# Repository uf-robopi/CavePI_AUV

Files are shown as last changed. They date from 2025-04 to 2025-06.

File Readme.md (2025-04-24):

This repository contains the design files, operational codes, and digital twin system's packages for the **CavePI AUV** (Autonomous Underwater Vehicle) from the RoboPI group at ECE, UF. The paper is accepted for publication at the Robotics: Science and Systems (RSS-2025). 

<p align="center">
  cavepi_field
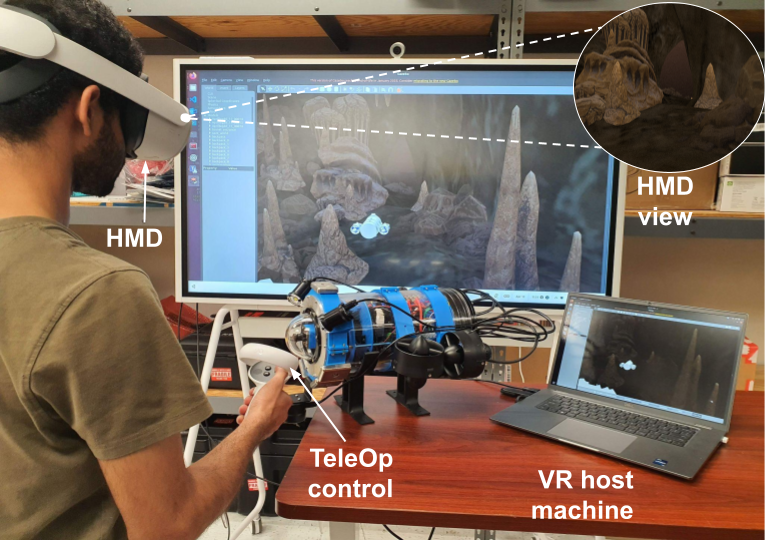
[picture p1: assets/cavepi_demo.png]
cavepi_demo
  
</p>

## Resources

- **Pointers:** [[ArXiv Pre-print]](https://arxiv.org/pdf/2502.05384) [[Project Page]](https://robopi.ece.ufl.edu/cavepi.html)  [[Video Demo]](https://youtu.be/9BPpB1nu98E)
- The subdirectories contain the following 
  - **CAD_designs:** Contains the SolidWork design files for all the parts used to build CavePI.
  - **auv_nano:** Contains the codes for CavePI's onboard Jetson device.
  - **auv_rpi:** Contains the codes for CavePI's onboard Raspberry Pi 5 device.
  - **auv_dt:** Contains the codes for ROS-Gazebo based digital twin (DT) of CavePI.

### License and Bibliography 
- Please check the LICENSE file 
- Citation entry:
	```
  @inproceedings{gupta2025demonstrating,
    title={Demonstrating CavePI: Autonomous Exploration of Underwater Caves by Semantic Guidance},
    author={Gupta, Alankrit and Abdullah, Adnan and Li, Xianyao and Ramesh, Vaishnav and Rekleitis, Ioannis and Islam, Md Jahidul},
    booktitle={Robotics: Science and Systems (RSS)},
    year={2025}
  }
	```

### Acknowledgements
This research is supported in part by the U.S. National Science Foundation (NSF) grants #2330416, #2024741, and #1943205; and the University of Florida (UF) Research grant #132763. We are thankful to Dr. Nare Karapetyan, Ruo Chen, and David Blow for facilitating our field trials at Ginnie open-water springs and Blue Grotto.

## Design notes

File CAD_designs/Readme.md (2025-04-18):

# SolidWork Design files of CavePI AUV

Due to large filesize of some parts, they are not uploaded directly to this repo. Please refer to this shared [Dropbox folder](https://www.dropbox.com/scl/fo/iza5p15aaolned5e47gp4/AAuj588nzsUPL_QK-2lGrOM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) to download all the files.

## Description

The parts are categorized into four groups.

- Exterior
  - Thruster
  - Sonar
  - Lights
  - ballast weights
- Interior (Computational enclosure)
  -  Battery junction
  -  Battery mounting plates (top, bottom, left, right, circular)
  -  Battery stack
  -  ESC
  -  Low light camera (downward camera)
  -  End cap
  -  O-ring flange
  -  Euro terminal strip
  -  Jetson Nano
  -  Mounting plate for Jetson Nano
  -  Raspberry Pi
  -  Mounting plate for Raspberry Pi
  -  Pixhawk
  -  Tether interface module
  -  Tube
-  Head
   - Fisheye camera
   - Dome connector
   - Dome retainer ring
   - Dome
 - Fasteners
   - Nuts, bolts, spacers and stand-offs

### Acknowledgements

We gratefully acknowledge the following entities for their the open-source CAD designs of various parts: Blue Robotics, GrabCAD, and McMaster-Carr.

| Part Name | 3D Model Owner / Referred From |
|---|---|
| Tube | Blue Robotics |
| End Cap | Blue Robotics |
| O-Ring Flange | Blue Robotics |
| Camera Low Light | Blue Robotics |
| Tether Interface Module | Blue Robotics |
| Basic ESC | Blue Robotics |
| Dome Retainer Ring | Blue Robotics |
| Dome | Blue Robotics |
| T200_Thruster | Blue Robotics |
| Sonar Bracket | Blue Robotics |
| Ping2 Sonar | Blue Robotics |
| Ballast Weight | Blue Robotics |
| Light | Blue Robotics |
| All fasteners | McMaster Carr |
| Jetson Nano | [GrabCAD](https://grabcad.com/library/nvidia-jetson-nano-2) |
| Raspberry Pi 5 | [GrabCAD](https://grabcad.com/library/raspberry-pi-5-2) |
| Pixhawk | [GrabCAD](https://grabcad.com/library/pixhawk-2-4-8-v1-flight-controller-1) |
| Fish-Eye Camera | [ArduCam](https://www.arducam.com/arducam-1080p-low-light-wdr-ultra-wide-angle-usb-camera-module-for-computer-2mp-cmos-imx291-160-degree-fisheye-mini-uvc-usb2-0-spy-webcam-boa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) |

## Example

The CAD assembly and the exploded view of CavePI is shown below:
<p align="center">
  cavepi_sys_gif
</p>

The 3D models of some of the parts in CavePI are shown below.
<p align="center">
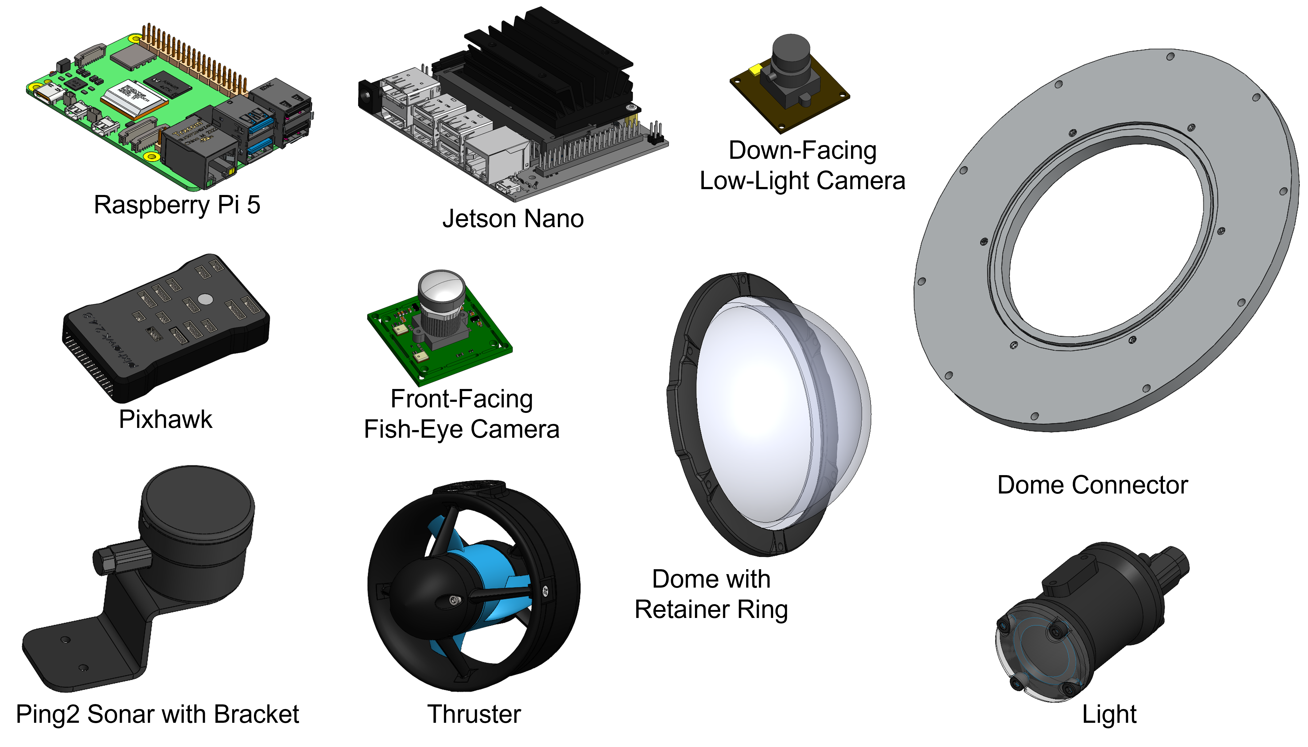
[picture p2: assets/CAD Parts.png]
CAD Parts
  
</p>

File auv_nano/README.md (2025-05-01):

# ROS2 Package for Perception of CavePI AUV

## Compatible Platform

The package is tested and verified on Jetson Orin Nano. It also runs on Jetson Nano 2GB with minimal modification in the code. Please refer to the `perception_utils.py` and comment/uncomment the codes where Jetson Nano and Jetson Orin Nano are mentioned.

Other specs (Platform dependent):

| | Jetson Nano 2GB | Jetson Orin Nano |
| ---  | ---  | --- |
| Ubuntu | 18.04 | 22.04 |
| ROS2 | Foxy | Humble |
| Jetpack | 4.6.3 | 6.0 |
| Python | 3.6.9 | 3.10.6 |
| Cuda | 10.2 | 12.1 |
| CuDNN | 8.2.1 | 9.1 |
| TensorRT | 8.2.1 | 8.6 |

## Usage

1. Clone the repo and place the `auv_nano` folder inside `~/ros2_ws/src/` directory of your jetson device.
2. Download the model weights from here: [Dropbox link](https://www.dropbox.com/scl/fo/6oin10fofx2k8ffhxluia/AJO9DvS03urmhyW1etIEWww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)
   
   You will find `.onnx` files as well as `.engine` files. If your platform matches the Jetson Nano 2GB configuration described above, you can directly use the `.engine` files. For different platforms such as Jetson Orin, download the `.onnx` file in your Jetson device and convert it to `.engine` format:
   ```sh
    /usr/src/tensorrt/bin/trtexec --onnx=<onnx_filename> --saveEngine=<engine_filename>
   ```
3. Create the `~/ros2_ws/src/auv_nano/weights/` directory and place the engine file there.
   ```sh
   mkdir -p ~/ros2_ws/src/auv_nano/weights/
   mv <path_to_your_engine_file> ~/ros2_ws/src/auv_nano/weights/
   ```
5. Set the `engine_filename` in `detector.py`. The default is `mobilenet.engine`.
6. Connect the two cameras to USB ports of your Jetson device. Check their port number using:
    ```sh
    v4l2-ctl --list-devices
    ```
7. Update the port numbers: `FRONT_CAMERA_INDEX` and `DOWN_CAMERA_INDEX` in `config/config.yaml`.  

8. Build the ROS package.
   ```sh
   cd ~/ros2_ws/
   colcon build --packages-select auv_nano
   ```
9. Execute the launch file. It will run the detector and planner node.
   ```sh
   ros2 launch auv_nano detector_and_planner.launch.py
   ```
   If a line is detected from the downward camera, the planner will send control commands to Raspberry Pi. Please refer to the `auv_rpi` folder to setup the Raspberry Pi codes.

## Example

If a caveline is detected, the `/processed_image` topic should look like the example below. Note that, the AUV is in motion and the blue arrow is indicating the next waypoint. 
<p align="center">
  Detection Tank
</p>

## Troubleshoot
Q: How to install pycuda on Jetson devices?

`pip install pycuda`

`fatal error: cuda.h: No such file or directory`

The following commands do the trick in Orin nano:

```sh
export PATH=/usr/local/cuda/bin:$PATH
sudo apt-get install python3-dev
pip install numpy
export CUDA_ROOT=/usr/local/cuda
pip install pycuda
```

Also see similar solutions reported across the community:
* https://forums.developer.nvidia.com/t/modulenotfounderror-no-module-named-pycuda-driver/204031
* https://stackoverflow.com/questions/52195608/src-cpp-cuda-hpp1410-fatal-error-cuda-h-no-such-file-or-directory/52604456

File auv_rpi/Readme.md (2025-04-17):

# ROS2 Package for Autopilot of CavePI AUV

## Compatible Platform

The package is tested and verified on Raspberry Pi 5 with ROS2 Humble.

## Connections
Connect the three USB ports of Raspberry Pi 5 to the ethernet port of Jetson Nano, micro USB port of the Pixhawk, and a USB to UART device to connect with the Ping2 sonar.

## Usage

1. Clone the repo and place the `auv_rpi` folder inside `~/ros2_ws/src/` directory of your Raspberry Pi 5.
2. Build the ROS package.
   ```sh
   cd ~/ros2_ws/
   colcon build --packages-select auv_rpi
   ```
3. Execute the launch file.
   ```sh
   ros2 launch auv_rpi cavepi_auv.launch.py
   ```
   If a caveline is detected from the downward camera, the AUV will start following the caveline.

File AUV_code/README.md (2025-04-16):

# ROS2 Package for Perception and Control of CavePI AUV

## Compatible Platform
Jetson Orin Nano 8GB

Jetpack 6

Python 3.10

Cuda xx

Tensor RT xx

## Usage:

1. Download and place this folder inside your `ros2_ws/src` directory.
2. Download the model weights from here: [Dropbox link](www.somelink.com)
   
   You will find .onnx files as well as .engine files. If your platform matches the configuration described above, you can directly use the .engine files. Otherwise, download the .onnx file in your Jetson device and convert it to .engine format:
   ```sh
    /usr/src/tensorrt/bin/trtexec --onnx=<onnx_filename> --saveEngine=<engine_filename>
   ```
4. Build the ROS package.
   ```sh
   colcon build --packages-select <package_name>
   ```
5. Run the caveline detector node.
   ```sh
   ros2 run detector caveline_detection_main.py
   ```

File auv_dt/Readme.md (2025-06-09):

# Digital Twin of CavePI AUV

## Compatible Platform

The packages are tested on ROS Noetic with Gazebo Classic.

## Additional Packages Installation
1. Install the `mavros` and `teleop-twist-keyboard` packages for the respective ROS version.
    ```sh
   sudo apt install ros-noetic-mavros ros-noetic-mavros-extras
   sudo apt install ros-noetic-teleop-twist-keyboard
   ```
   In case if you are using any other version of ROS than Noetic, please replace `noetic` with the correct version of ROS.
2. Install the `scipy` package with version >= 1.6.
   ```sh
   sudo apt install python3-pip
   pip3 install --user --upgrade scipy
   ```
   
## Usage

1. Clone the repo and place the four packages inside `~/catkin_ws/src/` directory in your local computer.
2. Download the 3D models of the CavePI links from here: [Dropbox link](https://www.dropbox.com/scl/fo/h16z4oh9wp337o5n7fm5i/AFeJVwF5MsPjYP4ErddTO0g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)
3. You will find a folder named `meshes` in the link. Download the folder and place it inside `~/catkin_ws/src/cavepi_description/`.
4. Build and source the ROS workspace.
   ```sh
   cd ~/catkin_ws/
   catkin_make
   source devel/setup.bash
   ```
6. For visualizing the digital twin model in RViz, run a ROS launch file:
   ```sh
   roslaunch cavepi_bringup display.launch
   ```
7. For autonomous caveline following, run a ROS launch file:
   ```sh
   roslaunch cavepi_bringup cavepi_auv.launch
   ```
8. For teleopration, run a ROS launch file:
   ```sh
   roslaunch cavepi_bringup cavepi_rov.launch
   ```
   And, also run a teleoperation node in another terminal window:
   ```sh
   rosrun cavepi_controller cavepi_teleop_keyboard.py
   ```
   By operating the keys as mentioned in the teleoperation node, digital twin can be controlled in the Gazebo environment.

### Acknowledgements

We gratefully acknowledge the [LoCO-AUV](https://github.com/loco-auv) for their open-source digital twin simulator.

## Example

The autonomous caveline following capability of the CavePI's digital twin is shown below. A red color caveline is arranged in a hexagonal shape at the bottom and CavePI is following it. Please note that CavePI's downward-facing camera view is also presented at the top-left corner of the gif below.
<p align="center">
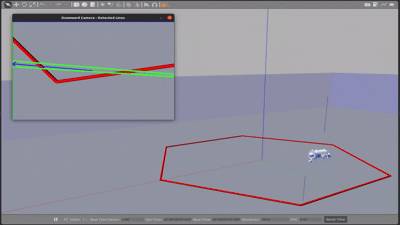
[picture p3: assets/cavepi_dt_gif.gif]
cavepi_dt_gif
  
</p>

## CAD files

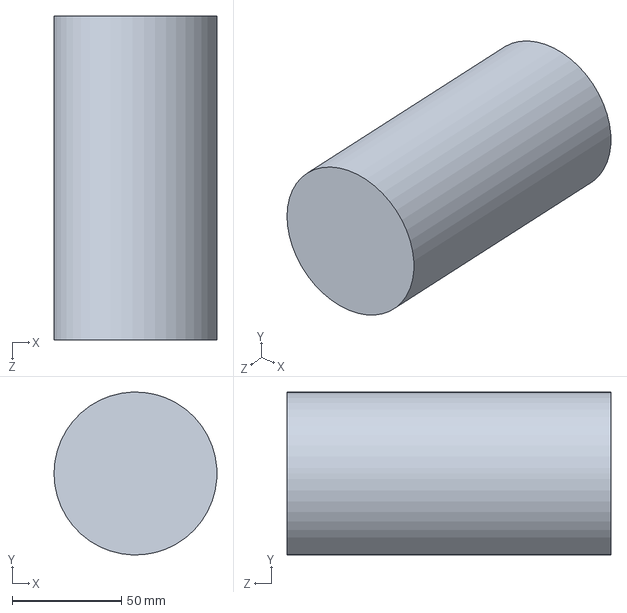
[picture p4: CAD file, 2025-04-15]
CAD_designs/Computational Enclosure/Battery Stack.SLDPRT
74.5 x 74.5 x 148.0 mm

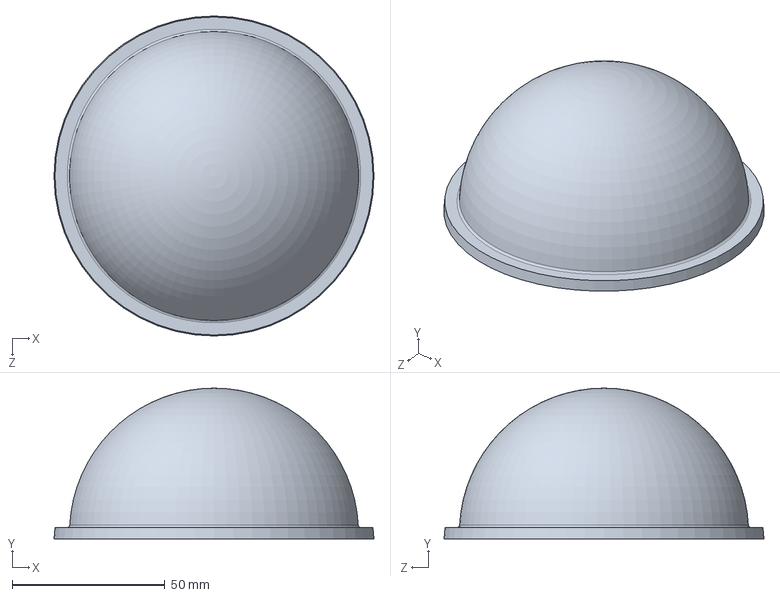
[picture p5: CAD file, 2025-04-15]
CAD_designs/Head/Dome.SLDPRT
104.7 x 49.3 x 104.7 mm

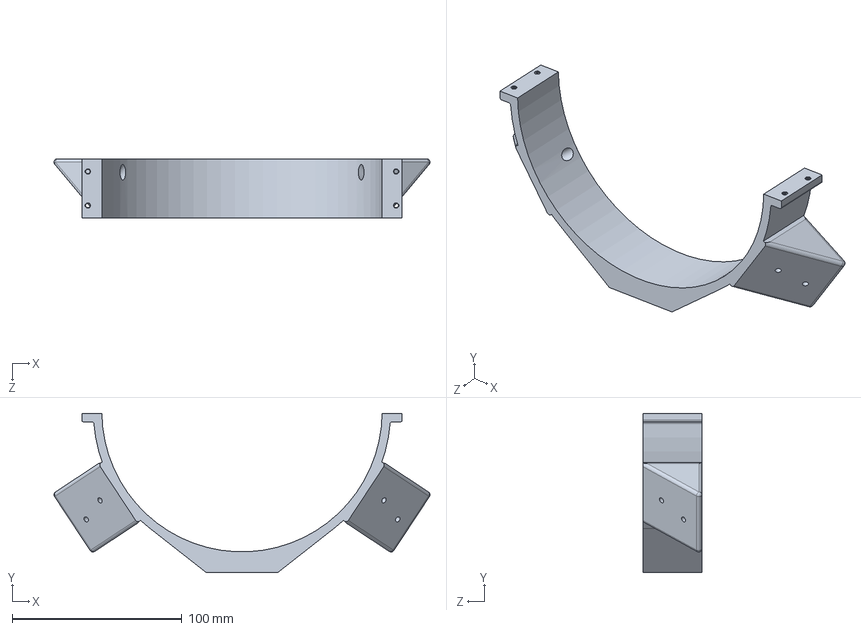
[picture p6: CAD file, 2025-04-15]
CAD_designs/Thrusters, Sonar, Lights, and Weights/Clamp for Sonar_Top.SLDPRT
221.5 x 93.8 x 35.0 mm

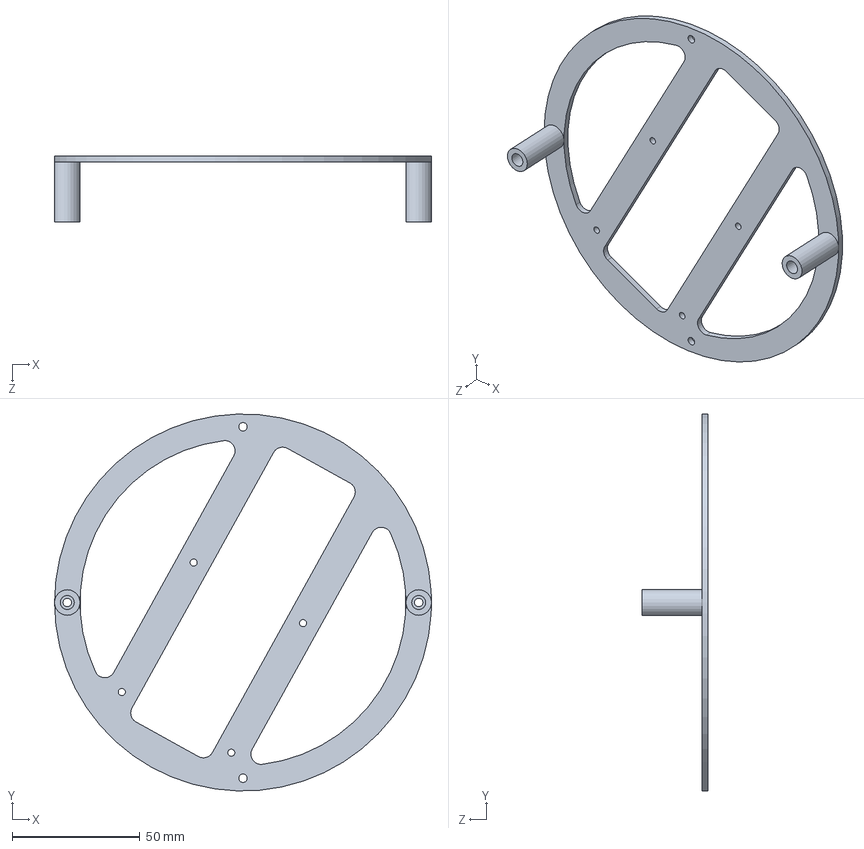
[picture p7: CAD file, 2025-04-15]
CAD_designs/Computational Enclosure/Mounting Plate_Raspberry Pi.SLDPRT
147.7 x 147.6 x 26.0 mm

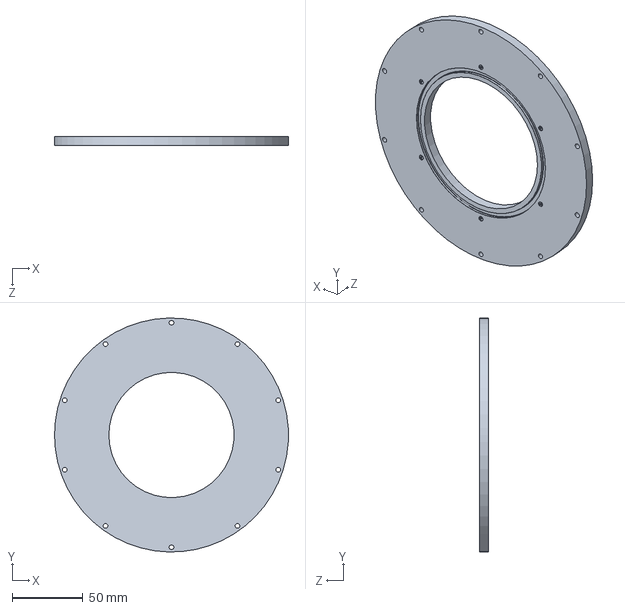
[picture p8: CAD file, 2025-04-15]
CAD_designs/Head/Dome Connector.SLDPRT
165.4 x 165.3 x 6.10 mm

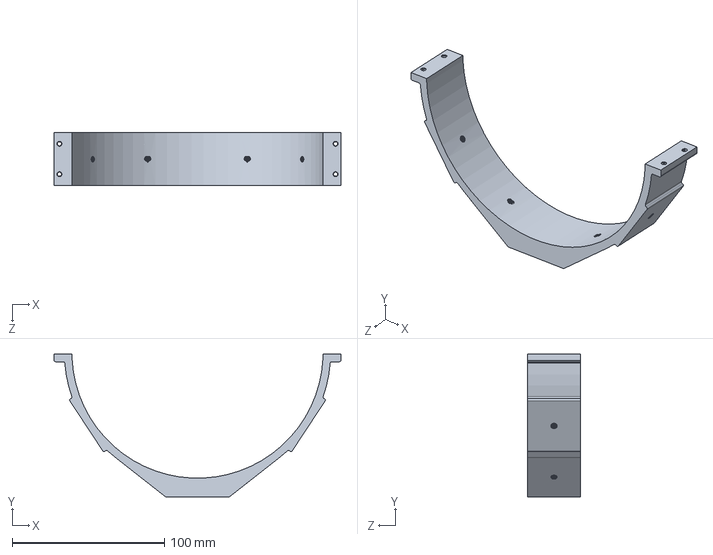
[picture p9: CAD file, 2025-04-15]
CAD_designs/Thrusters, Sonar, Lights, and Weights/Clamp for Sonar_Bottom.SLDPRT
188.7 x 93.8 x 35.0 mm

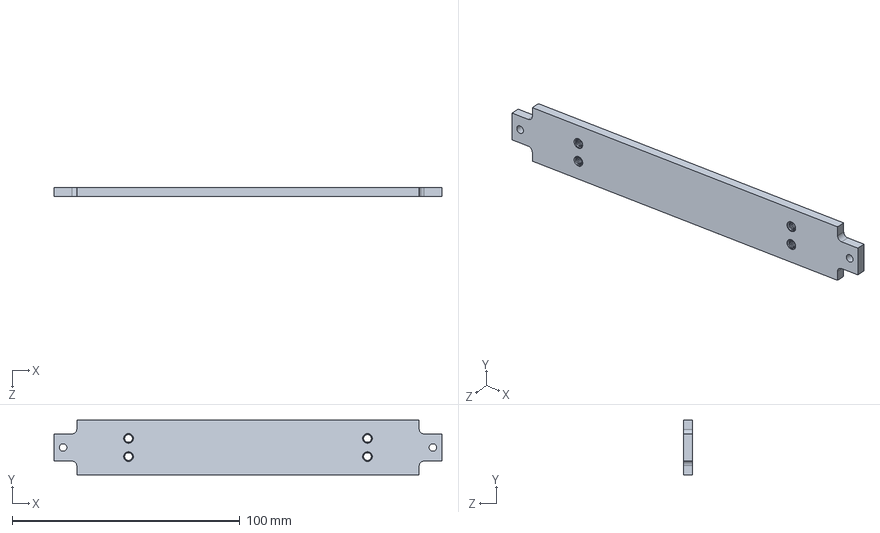
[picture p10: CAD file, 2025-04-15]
CAD_designs/Computational Enclosure/Battery Mounting_Top Plate.SLDPRT
170.5 x 24.0 x 3.90 mm

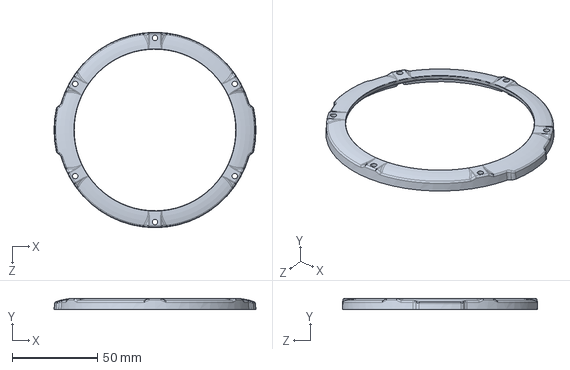
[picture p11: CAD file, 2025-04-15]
CAD_designs/Head/Dome Retainer Ring.SLDPRT
118.4 x 6.50 x 114.5 mm

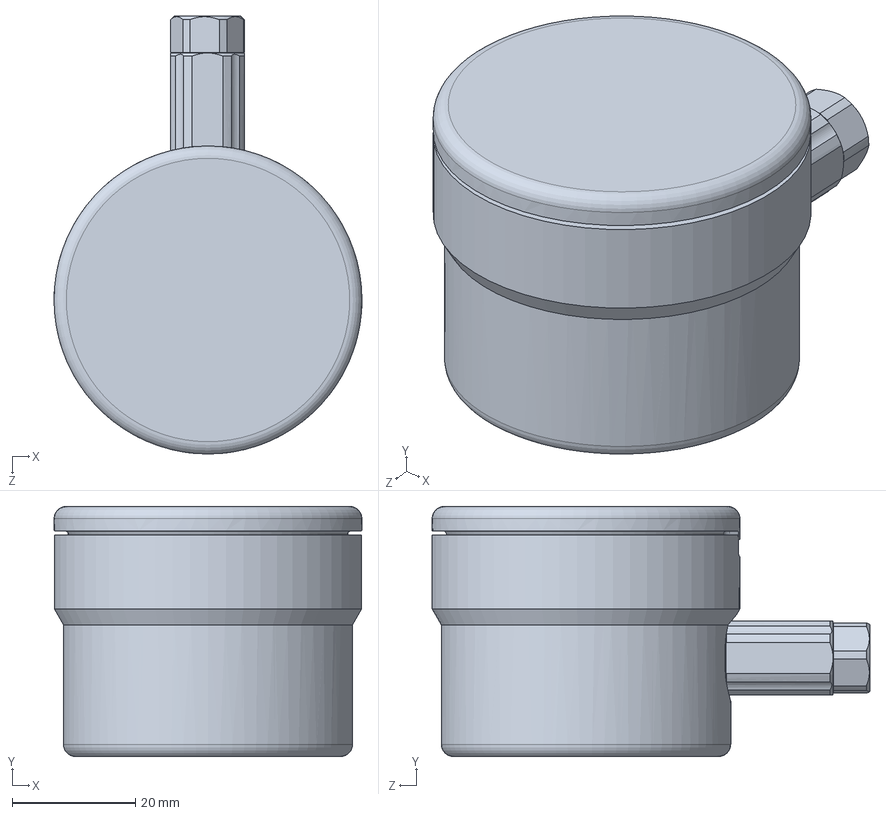
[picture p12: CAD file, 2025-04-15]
CAD_designs/Thrusters, Sonar, Lights, and Weights/Ping2 Sonar.SLDPRT
50.0 x 40.6 x 71.1 mm

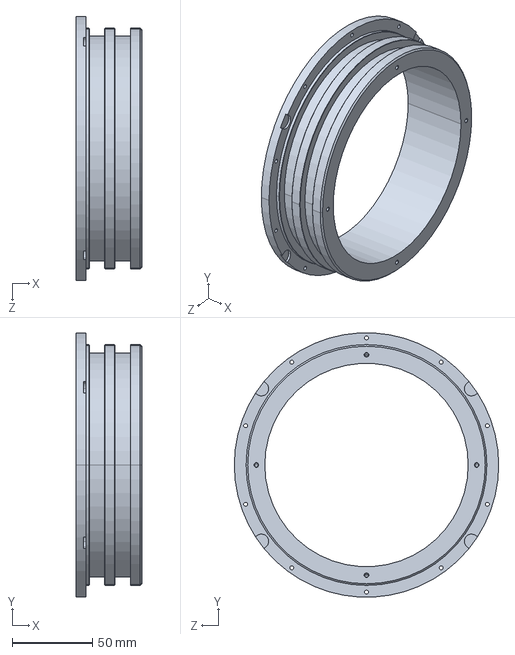
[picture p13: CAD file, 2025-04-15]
CAD_designs/Computational Enclosure/O-Ring Flange.SLDPRT
41.0 x 164.8 x 165.1 mm

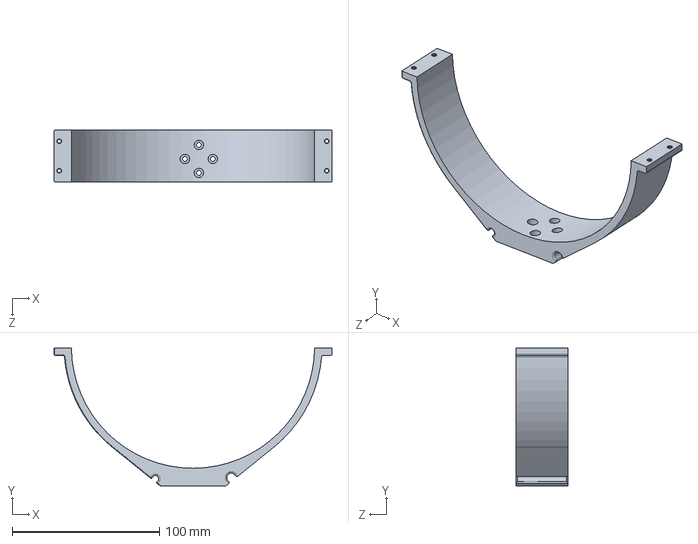
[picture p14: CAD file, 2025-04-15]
CAD_designs/Thrusters, Sonar, Lights, and Weights/Clamp for Horizontal Thrusters_Right.SLDPRT
188.7 x 93.5 x 35.0 mm

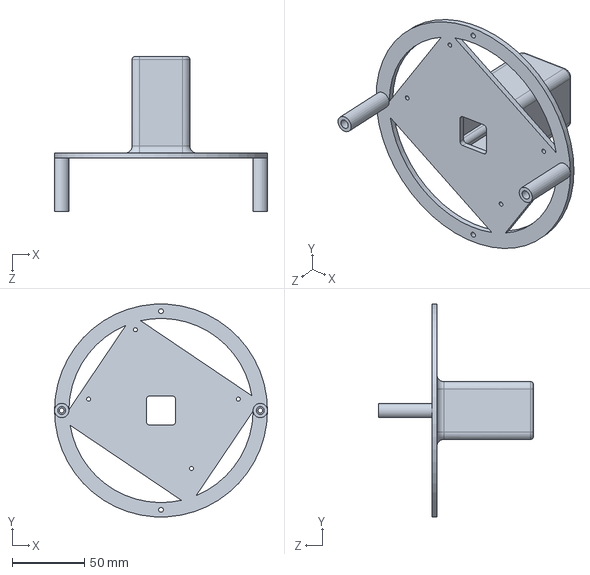
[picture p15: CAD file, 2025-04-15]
CAD_designs/Computational Enclosure/Mounting Plate_Jetson Nano.SLDPRT
147.7 x 147.4 x 107.5 mm

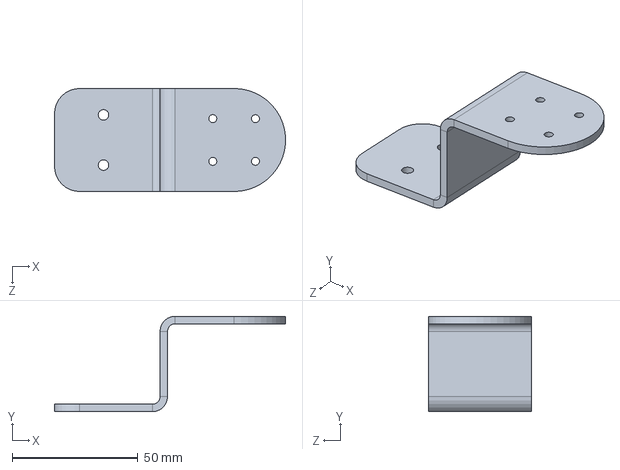
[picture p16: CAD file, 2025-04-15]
CAD_designs/Thrusters, Sonar, Lights, and Weights/Sonar Bracket.SLDPRT
92.0 x 38.0 x 41.0 mm

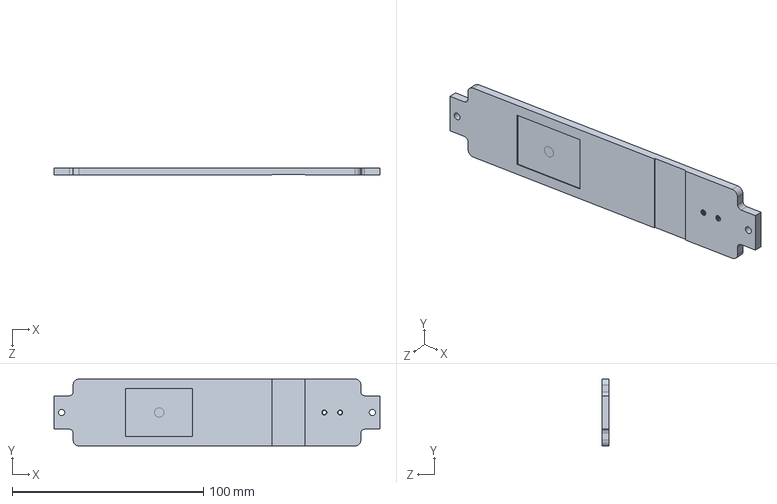
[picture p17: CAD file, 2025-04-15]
CAD_designs/Computational Enclosure/Battery Mounting_Right Plate.SLDPRT
170.5 x 35.0 x 3.90 mm

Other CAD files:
CAD_designs/Computational Enclosure/Raspberry Pi 5.SLDASM
CAD_designs/Thrusters, Sonar, Lights, and Weights/Clamp for Vertical Thrusters.SLDPRT
CAD_designs/Computational Enclosure/Pixhawk.SLDPRT
CAD_designs/Thrusters, Sonar, Lights, and Weights/Light.SLDPRT
CAD_designs/Computational Enclosure/Basic ESC.SLDPRT
CAD_designs/Computational Enclosure/Battery Junction.SLDPRT
CAD_designs/Computational Enclosure/Battery Mounting_Bottom Plate.SLDPRT
CAD_designs/Computational Enclosure/Battery Mounting_Circular Plate.SLDPRT
CAD_designs/Computational Enclosure/Battery Mounting_Left Plate.SLDPRT
CAD_designs/Computational Enclosure/Camera_Low Light.SLDPRT
CAD_designs/Computational Enclosure/End Cap.SLDPRT
CAD_designs/Computational Enclosure/Euro Terminal Strip.SLDPRT
CAD_designs/Computational Enclosure/Tether Interface Module.SLDPRT
CAD_designs/Computational Enclosure/Tube.SLDPRT
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

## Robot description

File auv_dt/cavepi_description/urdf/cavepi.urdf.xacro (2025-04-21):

<?xml version="1.0" ?>

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

<robot name="CavePI" xmlns:xacro="http://www.ros.org/wiki/xacro">

    <xacro:property name="tube_od" value="0.1651" />
    <xacro:property name="tube_id" value="0.1524" />
    <xacro:property name="tube_length" value="0.29845" />
    <xacro:property name="scale_size" value="1" />
    <xacro:property name="negligible_mass" value="1.0e-6" />
    <xacro:property name="negligible_inertia" value="1.0e-12" />
    <xacro:property name="negligible_volume" value="1.0e-9" />


    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
    <link name="base_link" />


    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
    <link name="main_body_link_cavepi">
        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

        <inertial>
            <origin xyz="${scale_size*-0.8e-3} 0 ${scale_size*-4.55e-3}" rpy="0 0 0" />
            <mass value="8.6" />
            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
        </inertial>
    </link>

    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
    <joint name="base_to_main_body_joint" type="fixed">
        <parent link="base_link" />
        <child link="main_body_link_cavepi" />
        <origin xyz="0 0 ${scale_size*tube_od/2}" rpy="0 0 0" />
    </joint>


    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
    <link name="front_right_thruster_link_cavepi">
        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
 
        <inertial>
            <origin xyz="0 0 ${scale_size*7.53e-3}" rpy="0 0 0" />
            <mass value="7.74e-3" />
            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
        </inertial>
    </link>
 
    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
    <joint name="body_to_fr_thruster_joint" type="continuous">
        <parent link="main_body_link_cavepi" />
        <child link="front_right_thruster_link_cavepi" />
        <origin xyz="0 ${scale_size*0.1435} 0" rpy="0 0 0"/>
        <axis xyz="0 0 1" />
    </joint>


    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
    <link name="front_left_thruster_link_cavepi">
        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
 
        <inertial>
            <origin xyz="0 0 ${scale_size*7.53e-3}" rpy="0 0 0" />
            <mass value="7.74e-3" />
            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
        </inertial>
    </link>
 
    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
    <joint name="body_to_fl_thruster_joint" type="continuous">
        <parent link="main_body_link_cavepi" />
        <child link="front_left_thruster_link_cavepi" />
        <origin xyz="0 ${scale_size*-0.1435} 0" rpy="0 0 0"/>
        <axis xyz="0 0 1" />
    </joint>


    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
    <link name="rear_right_thruster_link_cavepi">
        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
 
        <inertial>
            <origin xyz="0 0 ${scale_size*7.53e-3}" rpy="0 0 0" />
            <mass value="7.74e-3" />
            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
        </inertial>
    </link>
 
    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
    <joint name="body_to_rr_thruster_joint" type="continuous">
        <parent link="main_body_link_cavepi" />
        <child link="rear_right_thruster_link_cavepi" />
        <origin xyz="${scale_size*-0.09058} ${scale_size*0.1435} ${scale_size*0.004}" rpy="0 0 0"/>
        <axis xyz="1 0 0" />
    </joint>


    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
    <link name="rear_left_thruster_link_cavepi">
        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
 
        <inertial>
            <origin xyz="0 0 ${scale_size*7.53e-3}" rpy="0 0 0" />
            <mass value="7.74e-3" />
            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
        </inertial>
    </link>
 
    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
    <joint name="body_to_rl_thruster_joint" type="continuous">
        <parent link="main_body_link_cavepi" />
        <child link="rear_left_thruster_link_cavepi" />
        <origin xyz="${scale_size*-0.09058} ${scale_size*-0.1435} ${scale_size*0.004}" rpy="0 0 0"/>
        <axis xyz="1 0 0" />
    </joint>


    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
    <link name="downward_camera_link">
        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
 
        <inertial>
            <origin xyz="0 0 0" rpy="0 0 0" />
            <mass value="${negligible_mass}" />
            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
        </inertial>
    </link>
 
    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
    <joint name="body_to_down_cam_joint" type="fixed">
        <parent link="main_body_link_cavepi" />
        <child link="downward_camera_link" />
        <origin xyz="${scale_size*-0.04591} 0 ${scale_size*0.0687}" rpy="${-pi/2} ${-pi/2} 0"/>
    </joint>


    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
    <link name="front_camera_link">
        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
 
        <inertial>
            <origin xyz="0 0 0" rpy="0 0 0" />
            <mass value="${negligible_mass}" />
            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
        </inertial>
    </link>
 
    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
    <joint name="body_to_front_cam_joint" type="fixed">
        <parent link="main_body_link_cavepi" />
        <child link="front_camera_link" />
        <origin xyz="${scale_size*0.186} 0 0" rpy="${pi} 0 0"/>
    </joint>


    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
    <link name="ping2_sonar_link">
        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
 
        <inertial>
            <origin xyz="0 0 0" rpy="0 0 0" />
            <mass value="${negligible_mass}" />
            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
        </inertial>
    </link>
 
    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
    <joint name="body_to_sonar_joint" type="fixed">
        <parent link="main_body_link_cavepi" />
        <child link="ping2_sonar_link" />
        <origin xyz="${scale_size*0.18621} 0 ${scale_size*0.17343}" rpy="0 0 0"/>
    </joint>


    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
    <link name="bar30_sensor_link">
        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
 
        <inertial>
            <origin xyz="0 0 0" rpy="0 0 0" />
            <mass value="${negligible_mass}" />
            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
        </inertial>
    </link>
 
    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
    <joint name="body_to_bar30_joint" type="fixed">
        <parent link="main_body_link_cavepi" />
        <child link="bar30_sensor_link" />
        <origin xyz="${scale_size*-0.16684} 0 0" rpy="0 0 0"/>
    </joint>


    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
    <link name="imu_link">
        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
 
        <inertial>
            <origin xyz="0 0 0" rpy="0 0 0" />
            <mass value="${negligible_mass}" />
            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
        </inertial>
    </link>
 
    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
    <joint name="body_to_imu_joint" type="fixed">
        <parent link="main_body_link_cavepi" />
        <child link="imu_link" />
        <origin xyz="0 0 0" rpy="0 0 0"/>
    </joint>



    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
    

</robot>

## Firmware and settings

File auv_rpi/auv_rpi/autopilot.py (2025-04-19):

#!/usr/bin/env python3

# =====================================
# Author : Alakrit Gupta
# Email: gupta.alankrit@ufl.edu
# =====================================

import rclpy
from rclpy.node import Node
from std_msgs.msg import Float32, Int32, Bool, Float32MultiArray
from geometry_msgs.msg import Vector3
from pymavlink import mavutil
import time, sys, signal, math
import numpy as np
 
 
class AutopilotNode(Node):
    def __init__(self):
        super().__init__('autopilot')

        '''This is the 'autopilot' node sending control signals to the Pixhawk for CavePI's movement.'''
 
        # MAVLink setup
        self.master = mavutil.mavlink_connection('/dev/ttyACM0', baud=115200)
        self.master.wait_heartbeat()
        self.get_logger().info("Connected to Pixhawk.")
        self.boot_time = time.time()
        signal.signal(signal.SIGINT, self.signal_handler)
        

        # SUBSCRIBERS
        # QR Data Subscriber
        self.qr_subscriber = self.create_subscription(
            msg_type=Int32, topic='/qr_data', callback=self.callback_qr, qos_profile=10)
       
        # Depth-Hold State Information Subscriber
        self.depth_hold_subscriber = self.create_subscription(
            msg_type=Bool, topic='/depth_hold_state', callback=self.callback_depth_hold, qos_profile=10)
            
        # Sonar Data Subscriber
        self.sonar_data_subscriber = self.create_subscription(
            msg_type=Float32, topic='/adjusted_sonar_dist', callback=self.callback_sonar_dist, qos_profile=10)
       
        # Tracking Signal Subscriber
        self.tracking_subscriber = self.create_subscription(
            msg_type=Int32, topic='/tracking_signal', callback=self.callback_track_caveline, qos_profile=10)
            
        # Waypoints Subscriber
        self.waypoints_subscription = self.create_subscription(
            msg_type=Float32MultiArray, topic='/waypoints_data', callback=self.waypoints_callback, qos_profile=10)
        
        # Heading Angle Subscriber
        self.angle_subscriber = self.create_subscription(
            msg_type=Float32, topic='/angle_data', callback=self.angle_callback, qos_profile=10)
       
        # Pixhawk Arm/Disarm Information Publisher
        self.pixhawk_arm_publisher = self.create_publisher(
            msg_type=Bool, topic='/pixhawk_arm_state', qos_profile=10)


        # PUBLISHERS
        # IMU Data Publisher
        self.imu_publisher = self.create_publisher(
            msg_type=Vector3, topic='/imu_data', qos_profile=10)
        self.imu_timer = self.create_timer(timer_period_sec=0.275, callback=self.publish_imu_data)
        
        # Depth Data Publisher
        self.depth_publisher = self.create_publisher(
            msg_type=Float32, topic='/depth_data', qos_profile=10)
        self.depth_timer = self.create_timer(timer_period_sec=0.01, callback=self.publish_depth_data)
        
        # Pressure Data Publisher
        self.pressure_publisher = self.create_publisher(
            msg_type=Float32, topic='/pressure_data', qos_profile=10)
        
        # Depth Hold State Publisher
        self.stable_depth_publisher = self.create_publisher(
            msg_type=Bool, topic='/is_depth_hold_stabilized', qos_profile=10)


        # PARAMETER INITIALIZATION       
        # Tracking parameters
        self.is_turning = False
        self.straight_confirm_count = 0
        self.STRAIGHT_THRESHOLD = 3  # Threshold for confirming straight direction
        self.attitude = [0.0, 0.0, 0.0]
        self.next_heading_deg = 0.0
        
        # PID Controller Parameters
        self.kp_tracking = 3.4
        self.ki_tracking = 0.0
        self.kd_tracking = 0.9
        self.error_array = []
        self.dt_array = []
        self.previous_error = 0.0
        self.pid_last_time = None  
        self.error_integral = 0.0
        self.count_integrated_errors = 10
        self.max_turn_speed = 200

        # QR Code Detection Parameters
        self.invalid_qr = -1
        self.arm_pixhawk_qr = 1
        self.disarm_pixhawk_qr = 0
        self.qr_info = self.disarm_pixhawk_qr

        # Depth Hold Parameters
        self.is_depth_hold_started = False
        self.is_depth_hold_stabilized = False
        self.depth_hold_start_time = time.time()
        self.current_depth = 0.0 # meters
        self.target_depth = 0.35 # meters
        self.bottom_dist = 0.0 # meters
        self.safe_dist_from_bottom = 0.3 # meters
        self.kp_depth_hold = 600.0
        self.ki_depth_hold = 0.0
        self.kd_depth_hold = 50.0

        # Other Parameters
        self.is_pixhawk_armed = False
        self.manual_control_timer = self.create_timer(0.05, self.send_last_manual_control)  # 20 Hz
        self.last_manual_control = {"x": 0, "z": 500, "r": 0}


    def callback_qr(self, msg):
        '''
        Callback Function to Arm/Disarm The Vehicle Using QR Codes
        '''
        
        '''
        QR Data Interpretation
        -1: No/Invalid QR code shown
        0: Disarm the vehicle
        1: Arm the vehicle        
        ''' 
        previous_arm = self.is_pixhawk_armed
        previous_depth_hold = self.is_depth_hold_started
        previous_qr = self.qr_info
        self.qr_info = msg.data
       
        if self.qr_info != previous_qr:
            if self.qr_info == self.arm_pixhawk_qr:
                # If QR code is shown to arm the pixhawk, turn on the lights as well.
                self.turn_on_lights()
                self.is_pixhawk_armed = True
                self.arm_vehicle()
                self.get_logger().info("Vehicle is armed.")
            elif self.qr_info == self.disarm_pixhawk_qr:
                # If QR code is shown to disarm the pixhawk, turn off the lights as well.
                self.turn_off_lights()
                self.is_depth_hold_started = False
                self.is_pixhawk_armed = False
                self.disarm_vehicle()
                self.get_logger().info("Vehicle is disarmed.")
        elif self.qr_info == self.invalid_qr or self.qr_info == previous_qr:
            # In case of no/invalid/previous QR code, keep the AUV at its previous state.
            self.is_depth_hold_started = previous_depth_hold
            self.is_pixhawk_armed = previous_arm

        # Publish the Current Pixhawk Arm State
        pixhawk_arm_state = Bool()
        pixhawk_arm_state.data = self.is_pixhawk_armed
        self.pixhawk_arm_publisher.publish(pixhawk_arm_state)

        out = Bool()
        out.data = self.is_depth_hold_stabilized
        self.stable_depth_publisher.publish(out)
   
 
    def callback_depth_hold(self, msg):
        '''
        Callback Function for Taking Decision Regarding Depth Hold
        '''
        previous_depth_hold_state = self.is_depth_hold_started
        self.is_depth_hold_started = msg.data
        if self.is_depth_hold_started != previous_depth_hold_state:            
            if self.is_depth_hold_started:
                self.activate_depth_hold()
                self.get_logger().info("Depth Hold Activated!")   
            else:
                self.deactivate_depth_hold()
                self.get_logger().info("Depth Hold Deactivated!")
            
    
    def publish_depth_data(self):
        '''
        Function to Publish Depth Data
        '''
        try:
            msg = self.master.recv_match(blocking=False)
            if msg:
                msg_type = msg.get_type()
                if msg_type == 'SCALED_PRESSURE2':
                    pressure = Float32()
                    pressure.data = msg.press_abs
                    self.pressure_publisher.publish(pressure)
                    self.current_depth = self.calculate_depth_from_pressure(msg.press_abs)
                    depth_data = Float32()
                    depth_data.data = self.current_depth
                    self.depth_publisher.publish(depth_data)
                    # self.get_logger().info(f"Depth: {depth:.2f} meters")

                elif msg_type == 'ATTITUDE':
                    self.attitude[0] = math.degrees(msg.roll)  # Roll angle in degrees
                    self.attitude[1] = math.degrees(msg.pitch) # Pitch angle in degrees
                    self.attitude[2] = math.degrees(msg.yaw)   # Yaw angle in degrees
        except Exception as e:
            self.get_logger().error(f"Error reading data: {e}")
    
 
    def calculate_depth_from_pressure(self, pressure):
        '''
        Function to Calculate Depth from Pressure Data
        '''
        water_density = 1000 # kg/m^3  
        gravity = 9.81 # m/s^2
        reference_pressure = 1021.5 # hPa (Hecto Pascal)
        gauge_pressure = 100*(pressure - reference_pressure) # Pascal
        depth = gauge_pressure / (water_density * gravity)
        return depth
    

    def publish_imu_data(self):
        '''
        Function to Publish IMU Data
        '''
        try:
            imu_data = Vector3()
            imu_data.x = self.attitude[0]  # Roll angle in degrees
            imu_data.y = self.attitude[1]  # Pitch angle in degrees
            imu_data.z = self.attitude[2]  # Yaw angle in degrees
            self.imu_publisher.publish(imu_data)                
        except Exception as e:
            self.get_logger().error(f"Error reading data: {e}")
    

    def callback_sonar_dist(self, msg):
        '''
        Callback Function For Sonar Data
        '''
        distance = msg.data[0]
        confidence = msg.data[1]
        previous_dist = self.bottom_dist
        # Confidence of the sonar data decreases when it is not underwater.
        if confidence >= 90.0:
            self.bottom_dist = distance
        else:
            self.bottom_dist = previous_dist

 
    def waypoints_callback(self, msg):
        '''
        Callback Function for Waypoints
        '''
        waypoint = msg.data
        error_x = waypoint[0]
        error_y = waypoint[1]

    
    def angle_callback(self, msg):
        self.next_heading_deg = msg.data
 
 
    def callback_track_caveline(self, msg):
        '''
        Callback Function for Tracking Caveline
        '''
        tracking_signal = msg.data

        # Initializing parameters for thruster control     
        x = 0
        r = 0
        if self.bottom_dist > self.safe_dist_from_bottom:
            depth_diff = self.current_depth - self.target_depth
        else:
            # If the bottom distance is less than the safe distance, the target depth is adjusted to maintain a safe distance from the bottom.
            depth_diff = self.current_depth - self.target_depth - self.bottom_dist + self.safe_dist_from_bottom

        # Depth is controller by a PID
        # z = 500 + (self.kp_depth_hold * depth_diff)
        z = 500 + self.compute_pid_control(depth_diff, self.kp_depth_hold, self.ki_depth_hold, self.kd_depth_hold)
        z = np.clip(z, 200, 800)
        
        if not self.is_depth_hold_started:
            self.get_logger().info("Depth Hold is not active. Ignoring tracking signal.")
            self.depth_hold_start_time = time.time()
            return
        else:
            if 5 < time.time() - self.depth_hold_start_time < 15:
                self.send_manual_control(x, z, r)
                self.get_logger().info(f'z: {z}')
                return        
        self.is_depth_hold_stabilized = True

        '''
        TRACKING SIGNAL
        0: lost
        1: straight
        2: turn
        3: wait
        '''
        if tracking_signal == 1:
            if self.is_turning:
                # Confirm straight movement after completing a turn
                self.straight_confirm_count += 1
                if self.straight_confirm_count >= self.STRAIGHT_THRESHOLD:
                    self.is_turning = False
                    self.straight_confirm_count = 0
                    self.get_logger().info("Finished turning, moving straight.")
                    x = 190
                    r = 0
            else:
                x = 190
                r = -self.compute_pid_control(self.next_heading_deg, self.kp_tracking, self.ki_tracking, self.kd_tracking)
                r = np.clip(r, -self.max_turn_speed, self.max_turn_speed)
                
        elif tracking_signal == 2:
            self.straight_confirm_count = 0
            self.is_turning = True
            x = -30
            r = -self.compute_pid_control(self.next_heading_deg, 2*self.kp_tracking, self.ki_tracking, self.kd_tracking)
            r = np.clip(r, -self.max_turn_speed, self.max_turn_speed)
            if self.next_heading_deg < 0:
                self.get_logger().info("Turning right.")                
            else:
                self.get_logger().info("Turning left.")
        
        elif tracking_signal == 0:
            self.get_logger().info("Searching for caveline.")
            # If the caveline is lost from the view, CavePI rotates and tries to find the caveline.
            x = 0
            r = 200

        elif tracking_signal == 3:
            self.get_logger().info("Holding position.")
            x = 0
            r = 0
        
        self.send_manual_control(x, z, r)
        self.get_logger().info("callback_track_caveline funtion in pixhawk_logic node is called!")
 
 
    def compute_pid_control(self, error, kp, ki, kd):
        '''
        Function to Calculate PID Control Input
        '''
        current_time = time.time()
        if self.pid_last_time is None:
            dt = 0.1 # seconds
        else:
            dt = current_time - self.pid_last_time
        self.pid_last_time = current_time
        
        self.dt_array.append(dt)
        self.error_array.append(error)
        if len(self.error_array) > self.count_integrated_errors:
            self.error_array.pop(0)
            self.dt_array.pop(0)
        self.error_integral = np.dot(self.error_array, self.dt_array)
        error_derivative = (error - self.previous_error) / dt
        control_signal = (kp * error) + (ki * self.error_integral) + (kd * error_derivative)        
        self.previous_error = error

        return control_signal
        
    
    def arm_vehicle(self):
        '''
        Function to Arm the Vehicle
        '''
        # self.is_pixhawk_armed = True
        self.master.arducopter_arm()
        ack = self.master.recv_match(type='COMMAND_ACK', blocking=True, timeout=1)
        if ack and ack.result == mavutil.mavlink.MAV_RESULT_ACCEPTED:
            pass
        else:
            print("Arming failed or timed out.")
        manual_mode_id = self.master.mode_mapping()['MANUAL']
        self.master.set_mode(manual_mode_id)
        self.get_logger().info('Vehicle is armed in Manual mode!')
 
 
    def disarm_vehicle(self):
        '''
        Function to Disarm the Vehicle
        '''
        manual_mode_id = self.master.mode_mapping()['MANUAL']
        self.master.set_mode(manual_mode_id)
        self.get_logger().info("Vehicle is disarmed in Manual mode!")
        self.master.arducopter_disarm()
        self.master.motors_disarmed_wait()


    def turn_on_lights(self):
        '''
        Function to Turn On Lights
        '''
        # Turn both lights on (~1900us)
        self.set_servo(9, 1900)   # Light 1 on SERVO9
        self.set_servo(10, 1900)  # Light 2 on SERVO10
 
   
    def turn_off_lights(self):
        '''
        Function to Turn Off Lights
        '''
        # Turn both lights off (~1100us)
        self.set_servo(9, 1100)   # Light 1 on SERVO9
        self.set_servo(10, 1100)  # Light 2 on SERVO10


    def set_servo(self, channel, pwm):
        '''
        Function to Send Servo Signals
        '''
        self.master.mav.command_long_send(
            self.master.target_system,        # target_system
            self.master.target_component,     # target_component
            mavutil.mavlink.MAV_CMD_DO_SET_SERVO, # command
            0,                           # confirmation
            channel,                     # param1: servo channel
            pwm,                         # param2: PWM value
            0,0,0,0,0                   # param3-7 (unused)
        )

    
    def activate_stabilize_mode(self):
        '''
        Function to Activate Stabilize Mode in Pixhawk
        '''
        stabilize_mode = self.master.mode_mapping()['STABILIZE']
        self.master.mav.set_mode_send(
            self.master.target_system,
            mavutil.mavlink.MAV_MODE_FLAG_CUSTOM_MODE_ENABLED,
            stabilize_mode)
        self.get_logger().info('Stabilize Mode set!')


    def deactivate_depth_hold(self):
        '''
        Function to Deactivate Depth Hold Mode
        '''
        self.is_depth_hold_started = False
        self.activate_stabilize_mode()
        # self.disarm_vehicle()

    
    def activate_depth_hold(self):
        '''
        Function to Activate Depth Hold Mode
        '''
        # Direct enabling the Depth Hold mode and setting a depth was not working reliably. Hence, the stabilize mode is activated before the Depth Hold mode.
        self.activate_stabilize_mode()
        # self.get_logger().info(f'{self.master.mode_mapping()}')
        # time.sleep(2.0)
        
        depth_hold_mode = self.master.mode_mapping().get('ALT_HOLD', None)
        if depth_hold_mode is None:
            self.get_logger().error("Depth Hold mode not available.")
            return

        self.get_logger().info("Attempting to activate Depth Hold mode...")
        attempt = 0
        max_attempts = 5
        while attempt < max_attempts:
            msg = self.master.recv_match(type='HEARTBEAT', blocking=False)
            if msg and msg.custom_mode == 0: # 0 means 'STABILIZE MODE'
                self.master.set_mode(depth_hold_mode)
                msg = self.master.recv_match(type='HEARTBEAT', blocking=False)
                time.sleep(0.2)
                attempt += 1
            elif msg and msg.custom_mode == depth_hold_mode:
                # The set_target_depth() function was not working properly, hence a PID depth controller is implemented inside the callback_track_caveline() function.
                # self.set_target_depth(self.target_depth)
                # self.get_logger().info(f"Target depth set to {self.current_depth} meters below the surface.")
                # time.sleep(0.5)
                return
        self.get_logger().error("Failed to activate Depth Hold mode after multiple attempts.")     
        

    def set_target_depth(self, depth):
        '''
        Function to Set The Depth for Depth Hold Mode
        '''
        self.master.mav.set_position_target_global_int_send(
            int(1e3 * (time.time() - self.boot_time)), # ms since boot
            self.master.target_system, self.master.target_component,
            mavutil.mavlink.MAV_FRAME_GLOBAL_INT,
            ( # ignore everything except z position
                mavutil.mavlink.POSITION_TARGET_TYPEMASK_X_IGNORE |
                mavutil.mavlink.POSITION_TARGET_TYPEMASK_Y_IGNORE |
                # DON'T mavutil.mavlink.POSITION_TARGET_TYPEMASK_Z_IGNORE |
                mavutil.mavlink.POSITION_TARGET_TYPEMASK_VX_IGNORE |
                mavutil.mavlink.POSITION_TARGET_TYPEMASK_VY_IGNORE |
                mavutil.mavlink.POSITION_TARGET_TYPEMASK_VZ_IGNORE |
                mavutil.mavlink.POSITION_TARGET_TYPEMASK_AX_IGNORE |
                mavutil.mavlink.POSITION_TARGET_TYPEMASK_AY_IGNORE |
                mavutil.mavlink.POSITION_TARGET_TYPEMASK_AZ_IGNORE |
                # DON'T mavutil.mavlink.POSITION_TARGET_TYPEMASK_FORCE_SET |
                mavutil.mavlink.POSITION_TARGET_TYPEMASK_YAW_IGNORE |
                mavutil.mavlink.POSITION_TARGET_TYPEMASK_YAW_RATE_IGNORE
            ), 
            0, 0, -depth, # (x, y WGS84 frame pos - not used), z [m]
            0, 0, 0, # velocities in NED frame [m/s] (not used)
            0, 0, 0, 0, 0
            # accelerations in NED frame [N], yaw, yaw_rate
            #  (all not supported yet, ignored in GCS Mavlink)
        )
       
       
    def send_manual_control(self, x, z, r):
        '''
        Function for continuously sending control commands to Pixhawk
        '''
        self.last_manual_control["x"] = int(x)
        self.last_manual_control["z"] = int(z)
        self.last_manual_control["r"] = int(r)
        self.master.mav.manual_control_send(
            self.master.target_system,
            int(x),  # Forward movement    # Range [-1000, 1000]
            0,       # No lateral movement # Range [-1000, 1000]
            int(z),  # Constant throttle   # Range [0, 1000]
            int(r),  # Rotation            # Range [-1000, 1000]
            0        # No button press
        )

    def send_last_manual_control(self):
        self.master.mav.manual_control_send(
            self.master.target_system,
            self.last_manual_control["x"],
            0,
            self.last_manual_control["z"],
            self.last_manual_control["r"],
            0
        )

        
    def signal_handler(self, sig, frame):
        """Handle CTRL+C for cleanup."""
        self.get_logger().info("Interrupt received. Disarming ROV and exiting.")        
        try:
            self.shutdown_state = True
            self.turn_off_lights()
            self.is_depth_hold_started = False
            self.is_pixhawk_armed = False
            self.disarm_vehicle()
            self.master.close()
        except Exception as e:
            self.get_logger().error(f"Error closing Pixhawk connection: {e}")
        sys.exit(0)
   
 
def main(args=None):
    rclpy.init(args=args)
    node = AutopilotNode()
 
    try:
        rclpy.spin(node)
    except Exception as e:
        node.get_logger().error(f"Error occurred: {e}")
        node.turn_off_lights()
        node.is_depth_hold_started = False
        node.is_pixhawk_armed = False
        node.disarm_vehicle()
    finally:
        node.destroy_node()
        rclpy.shutdown()
 
 
if __name__ == '__main__':
    main()

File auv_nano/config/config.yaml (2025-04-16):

# =======================================================
# Author : Alakrit Gupta, Adnan Abdullah
# Email: gupta.alankrit@ufl.edu, adnanabdullah@ufl.edu
# =======================================================

# Camera index
FRONT_CAMERA_INDEX: 0
DOWN_CAMERA_INDEX: 4

# Camera attempt parameters
MAX_ATTEMPTS: 10
REINIT_ATTEMPTS: 5


# Camera attempt parameters
FRAME_WIDTH: 640
FRAME_HEIGHT: 480
FRAME_FPS: 30

# Publish rate (Hz) - how often we process frames and send data
PUBLISH_RATE: 5.0  # 5 Hz

# UDP settings
UDP_IP: "192.168.3.2"
UDP_PORT: 5005

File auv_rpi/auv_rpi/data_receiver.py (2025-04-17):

#!/usr/bin/env python3

# =====================================
# Author : Alakrit Gupta
# Email: gupta.alankrit@ufl.edu
# =====================================

import rclpy
from rclpy.node import Node
from std_msgs.msg import String, Float32MultiArray, Int32, Float32
import socket, json, threading, time

class DataReceiver(Node):
   def __init__(self):
       super().__init__('data_receiver')

       '''This node is collecting the data sent from Jetson Nano through udp and publishing them in appropriate ROS topics.'''
    
       self.udp_ip = "0.0.0.0"
       self.udp_port = 5005
       self.sock = socket.socket(socket.AF_INET, socket.SOCK_DGRAM)
       self.sock.bind((self.udp_ip, self.udp_port))
       
       self.qr_publisher = self.create_publisher(
           msg_type=Int32, topic='/qr_data', qos_profile=10)
       self.state_publisher = self.create_publisher(
           msg_type=String, topic='/state_data', qos_profile=10)
       self.waypoints_publisher = self.create_publisher(
           msg_type=Float32MultiArray, topic='/waypoints_data', qos_profile=10)
       self.angle_publisher = self.create_publisher(
           msg_type=Float32, topic='/angle_data', qos_profile=10)
       
       self.thread = threading.Thread(target=self.receive_udp_data)
       self.thread.daemon = True
       self.thread.start()
   
   
   def receive_udp_data(self):
       '''
       Function to Receive Data Through UDP
       '''
       while True:
           try:
               data, addr = self.sock.recvfrom(1024) 
               message = json.loads(data.decode('utf-8'))
               data_type = message.get('type')
               payload = message.get('data')
               if data_type == 'qr_info':
                   self.publish_qr_data(payload)
               elif data_type == 'state':
                   self.publish_state_data(payload)
               elif data_type == 'waypoints':
                   self.publish_waypoints_data(payload)
               elif data_type == 'angle':
                   self.publish_angle_data(payload)
               else:
                   self.get_logger().warn(f"Unknown data type received: {data_type}")
           except Exception as e:
               self.get_logger().error(f"Error receiving or processing data: {e}")


   def publish_qr_data(self, data):
       '''
       Function to Publish QR Data in ROS Topic
       '''
       msg = Int32()
       msg.data = data.get('qr_data', '')
       self.qr_publisher.publish(msg)
   
   
   def publish_state_data(self, data):
       '''
       Function to Publish State Data in ROS Topic
       '''
       msg = String()
       msg.data = data.get('direction', '')
       self.state_publisher.publish(msg)
   
   
   def publish_waypoints_data(self, data):
       '''
       Function to Publish Waypoints Data in ROS Topic
       '''
       msg = Float32MultiArray()
       x = data.get('x', 0.0)
       y = data.get('y', 0.0)
       msg.data = [x, y]
       self.waypoints_publisher.publish(msg)


   def publish_angle_data(self, data):
       '''
       Function to Publish Angle Data in ROS Topic
       '''
       msg = Float32()
       msg.data = data.get('angle', 0.0)
       self.angle_publisher.publish(msg)


def main(args=None):
   rclpy.init(args=args)
   node = DataReceiver()
   try:
       rclpy.spin(node)
   except KeyboardInterrupt:
       pass
   finally:
       node.destroy_node()
       rclpy.shutdown()

if __name__ == '__main__':
   main()

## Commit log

2025-04-16 old codes
    [Ballast Weight.SLDPRT, Basic ESC.SLDPRT, Battery Junction.SLDPRT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]
2025-04-17 jetson package sturcture
2025-04-17 jetson modules
2025-04-18 author info
    [cavepi.urdf.xacro]
